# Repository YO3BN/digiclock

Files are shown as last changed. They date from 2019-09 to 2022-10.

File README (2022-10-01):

Configure:
==========

To prepare for compilation run the configure script with needed arguments.
Like the following:

./configure --uos ../../uOS --cpu atmega1284 --freq 1000000 --src lcd --src Si5351_ex

Compile:
========

make

To Clean:
=========

make clean
or
make distclean

How to flash:
=============

sudo avrdude -c usbtiny -p m1284 -U flash:w:./bin/firmware.hex:i
or
avrdude -P /dev/ttyUSB0 -c stk500v1 -b9600 -p m1284 -U flash:w:bin/firmware.hex:i

Read fuses (usually are shown when flashing)
==========

sudo avrdude -c usbtiny -p m1284 -U efuse:r:-:h
sudo avrdude -c usbtiny -p m1284 -U hfuse:r:-:h
sudo avrdude -c usbtiny -p m1284 -U lfuse:r:-:h

Their value must be:
avrdude: safemode: Fuses OK (E:FF, H:D8, L:62)

The original values were:
avrdude: safemode: Fuses OK (E:FF, H:99, L:62)

If the CPU frequency is 1MHz, the prescaler in uOS/arch/avr/atmega*/timers.c should be 1!

Write Hfuse
===========

To disable JTAG and activate the bootloader section at boot:
sudo avrdude -c usbtiny -p m1284 -U hfuse:w:0xD8:m

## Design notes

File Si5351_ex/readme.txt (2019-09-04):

This page contains some example code for the Si5351A synthesiser module chip.
There are a couple of other Si5351A libraries on the internet. However they
are either incomplete (don't go all the way from specifying a frequency, to
generating and setting the configuration registers), or quite over-complex.
Some are designed to cater for all the variants of the Si5351 (A/B/C) and all
the features. There's a Linux Si5351 driver but the code is very confusing and
anyway it does not seem well-suited to a limited-space microcontroller
environment.

So, with these C examples I have tried to keep it very simple, just to show
what needs to be done to get some output out of the Si5351A (only), and only
the 10-pin MSOP version with 3 outputs. From here, you can build on it, piece
by piece, to customise it for your application. So these examples generate a
10MHz signal on the Clk0 output, that's all. You can choose any frequency in
the range 1-150MHz, in the function call.

For frequencies under 1MHz, you need to employ the final divider stage in the
Si5351A, which can divide by powers of 2 from 1 to 128. So for example, if you
want 100kHz, then one way to do it is to configure the chip for a frequency of
1.6MHz, then configure the final division stage as divide-by-16 to get to
100kHz output. Using the division ratios, according to the datasheet, the
Si5351A can then generate low output frequencies from 8kHz to 1MHz.

For frequencies above 150MHz, and to the maximum specified frequency of 160MHz
according to the datasheet, some special configuration is required. I haven't
attempted to tackle that in this example code.
Useful documents

The Si5351A datasheet:
http://www.silabs.com/Support%20Documents/TechnicalDocs/Si5351-B.pdf
Manually generating an Si5351A register map:
http://www.silabs.com/Support%20Documents/TechnicalDocs/AN619.pdf

Application note AN619 "Manually generating an Si5351A register map" is much
more useful than the actual Si5351A datasheet. I refer to it often. There are
quite a lot of mistakes and confusions in both the datasheet and AN619 but all
of the information is actually in there and it can be decyphered.
Some theoretical discussion

The Si5351A is confugured using two signals, an I2C bus protocol. The QRP Labs
Si5351A module kit includes all the necessary pullups and level conversion to
run on a 5V microcontroller system. You only need to connect these two wires
to the AVR processor. It is important to understand the basic synthesis
mechanism of the Si5351A. There are really three stages to it:

1) A digital PLL multiplies the 27MHz crystal oscillator frequency up, to an
internal frequency; somewhere (that you configure) that must be in the range
600-900MHz. The multiplication factor is fractional, not an integer. The code
must configure all the registers that specify the integer part, and the
numerator/denominator of the fractional part. The integer part must be in the
range 15..90; the numerator 0..1048575 (20 bits), and the denominator
1..1048575 (also 20 bits). There are TWO PLLs available, PLL A and PLL B.

2) A divider stage divides this internal UHF frequency back down to the
desired output frequency. The division ratio is also fractional with 20-bit
fractional parts. However for best jitter performance the datasheet recommends
using even integers for the division factor. There are THREE "multisynth"
divider stages, one for each of the three Clk outputs of the Si5351A (other
variants of the Si5351A have 8 outputs, and various other input arrangements;
we aren't considering those here, we're keeping it simple, remember). Each
Multisynth divider can be fed by either of the two PLL outputs, you choose.

3) Finally there is also a final division stage for each output, which divides
by a power-of-2 factor of 1..128, this is needed for low frequency outputs in
the range 8kHz to 1MHz.

Since there are 2 PLLs and 3 outputs, and each output "multisynth" divider can
be fed from either of the two PLLs, if you want to set this up for multiple
outputs you have to do some tough thinking. If you stick to the "even integer"
divider, you don't really have THREE independent flexible output frequencies,
you have only two. Because two of those outputs are going to have to feed off
the same PLL. If there is not a convenient integral relationship between two
of the output frequencies, then for one of them you have to abandon the "even
integer division" rule for low jitter.

Anyway, I'm just saying. All of these things are considerations to take into
account. But not part of my simple simple example here.
Simple example code

The example code is written in C for AVR microcontrollers, I use the GCC
compiler in AVR Studio. It should be easy to use this on any AVR, or on the
Arduino platform. Only minor changes would be needed for other
microcontrollers.

There are TWO examples here. The first example allows you to use ANY I/O pins
of the processor to bit-bang as I2C. That gives a lot of flexibility, if you
happen to be using I/O pins other than the AVR's onboard I2C peripheral (they
call it the Two Wire interface in the Atmel datasheets and application notes),
or if you are using an AVR device that doesn't have an I2C peripheral onboard:
not all support I2C. In this example we use a very nice assembly language
library by Peter Fleury to take care of the I2C bit-banging. It works
perfectly!

The second example uses the AVR's internal I2C peripheral (which they call the
Two Wire interface, TWI, in the datasheets and application notes). That
assumes that in your application, your chosen AVR does have a TWI peripheral,
and that you aren't using those particular I2C pins of the processor for
something else, so you can afford to dedicate them to I2C purposes. This is
the ideal situation.

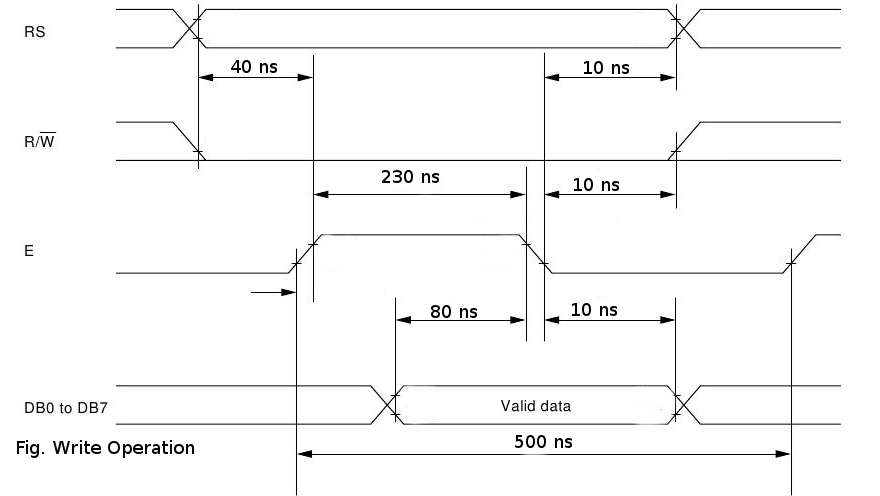
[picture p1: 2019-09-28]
hd44780/docs/write.png

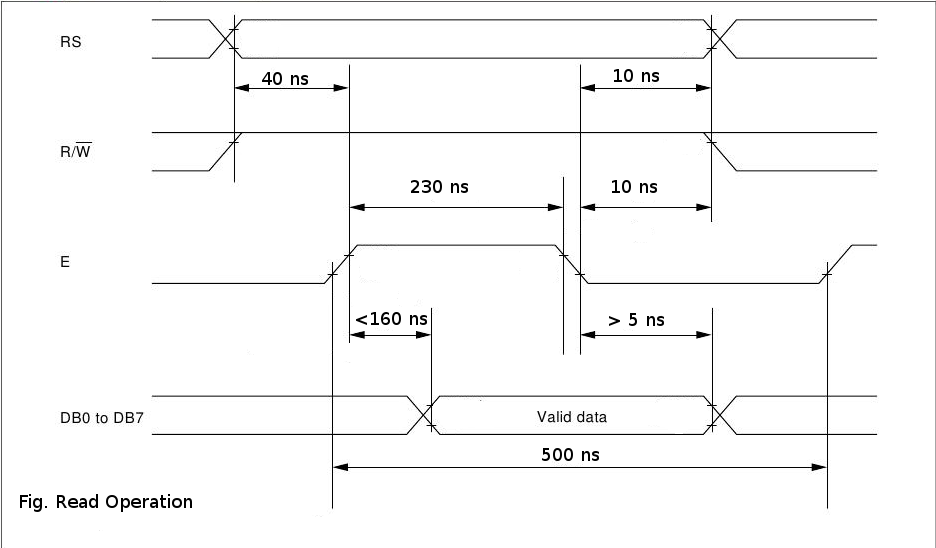
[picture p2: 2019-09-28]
hd44780/docs/read.png

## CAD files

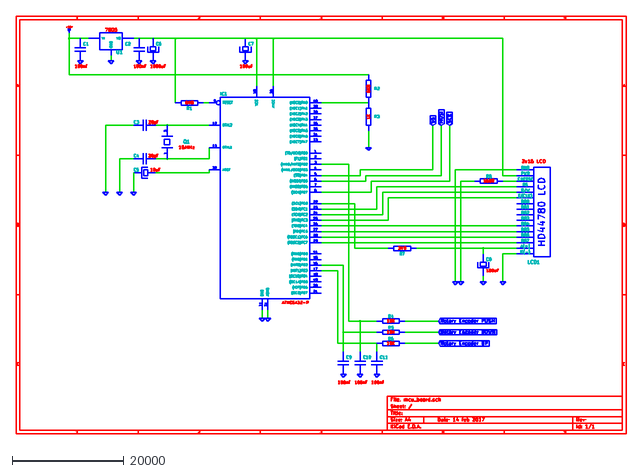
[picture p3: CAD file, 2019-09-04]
schematic/schematic.dxf
109000.0 x 74670.0

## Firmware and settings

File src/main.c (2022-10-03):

#include <stdio.h>
#include <stdlib.h>
#include <string.h>
#include <avr/io.h>
#include <util/delay.h>
#include <avr/sfr_defs.h>
#include <avr/interrupt.h>

#include "lcd.h"
#include "keypad.h"
#include "itu_table.h"
#include "si5351a.h"

#include "arch.h"
#include "kernel_api.h"

#include "drivers.h"
#include "uart.h"


typedef enum BFO_MODE_tag {
	LSB = 1,
	USB = 2,
} eBFO_Mode;


typedef enum IF_OPERATION_tag {
	IF_OPER_NONE = 0,
	IF_OPER_ADD = 1,
	IF_OPER_SUB = 2,
} eIF_OPERATION;


// TODO these should be stored in eeprom
#define IF_CENTER 10700000
#define IF_ECART 3000

static eBFO_Mode eBfo = LSB;
static eIF_OPERATION eIFOp = IF_OPER_ADD;
static int16_t IfEcart = IF_ECART;
static uint32_t if_center = IF_CENTER;
static uint8_t fine_tune = 0;

extern uint32_t xtalFreq;

typedef enum
{
	SCAN_NONE = 0,
	SCAN_WAIT,
	SCAN_UP,
	SCAN_DOWN,
} eScan;

static volatile eScan scan = SCAN_NONE;
static uint16_t scan_time = 5;

typedef enum eMENU_ENTRY_tag
{
	MENU_ENTRY_NONE = 0,
	MENU_ENTRY_FREQ_SET,
	MENU_ENTRY_FREQ_CURSOR,
	MENU_ENTRY_IF_ECART,
	MENU_ENTRY_BFO_MODE,
	MENU_ENTRY_BFO_OFFSET,
	MENU_ENTRY_BACKLIGHT,
	MENU_ENTRY_SICLK,
	MENU_ENTRY_SCNTIME,
	MENU_ENTRY_IFCENTER,
	MENU_ENTRY_EPROM_SAVE,
	MENU_ENTRY_EPROM_ERASE,
	MENU_ENTRY_EXIT,
}eMENU_ENTRY;

static eMENU_ENTRY eMenuEntry = MENU_ENTRY_FREQ_SET;


static int32_t offset_freq = 0;


struct frequency
{
	uint32_t hz;
	uint32_t step;
} frequency;


struct eprom_data
{
	uint32_t home_freq;
	uint32_t if_center;
	uint32_t si5351_qrtz;
	uint32_t if_width;
	int32_t  if_offset;
	// TODO: add checksum of all elements stored to eprom.
} eprom_data;


static volatile uint8_t event = 0;
extern volatile uint8_t keypad_event;
extern uint32_t xtalFreq;

#define	DIAL_UP		1
#define DIAL_DOWN	2
#define PUSH_BTN	3
#define KEYPAD		4

#define LCD_FREQ_POSITION	7
#define LCD_SMTR_POSITION	0x40


static volatile uint8_t encoder = 0;
static uint8_t show_agc_dB = 0;


/* the index is used as dB count. */
static uint16_t
agc_to_dB_table[] = {
	1023,
	894,
	718,
	650,
	608,
	575,
	549,
	526,
	505,
	487,
	469,
	453,
	435,
	420,
	406,
	393,
	380,
	368,
	356,
	345,
	334,
	323,
	312,
	301,
	293,
	284,
	276,
	268,
	260,
	252,
	245,
	238,
	231,
	224,
	219,
	213,
	208,
	203,
	198,
	194,
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
};


uint16_t audio_to_dB_table[] = {
	528,
	530,
	531,
	532,
	534,
	535,
	536,
	538,
	539,
	540,
	542,
	544,
	547,
	550,
	554,
	558,
	563,
	569,
	576,
	581,
	587,
	596,
	606,
	616,
	626,
	641,
	657,
	669,
	686,
	707,
	726,
	753,
	777,
	808,
	816,
	1023
};


ISR(PCINT3_vect)
{

static volatile uint8_t a = 0;
static volatile uint8_t isr = 0;
static volatile uint8_t byte = 0;
static volatile uint8_t x = 0;

	isr = ((PIND & 0b00110000) >> 4);
	if ((PIND & 0b00001000) == 0)
	{
		encoder = PUSH_BTN;
	}

	if (isr != a )
	{
		if (isr == 2 || isr == 0 || isr == 1)
		{
			byte |= isr;
			byte <<= 2;
			x++;
		}

		if ((x >= 3) && ((byte == 0x84) || (byte == 0x48)))
		{
			switch (byte)
			{
				case 0x84:
				encoder = DIAL_UP;
				break;

				case 0x48:
				encoder = DIAL_DOWN;
				break;

				default:
				break;
			}
			byte = 0;
			x = 0;
		}
		a = isr;
	}
}


uint8_t encoder_read(void)
{
	uint8_t ret = 0;

	switch (encoder)
	{
		case 1:
		case 2:
		case 3:
			ret = encoder;
			encoder = 0;
			break;

		default:
		break;
	}

	return ret;
}


void putch_freq(char c, char pos)
{
	lcd_command(LCD_SETDDRAMADDR | pos);
	lcd_write(c);
}

void show_freq(const char *s)
{
	char *p;
	char x = 0;
	char lcd_freq_pos = 15;

	/* p points to the end of the string */
	p = s + strlen(s) - 1;

	while (p >= s)
	{
		putch_freq(*p, lcd_freq_pos--);
		x++;

		if (!(x % 3) && (p - s > 0))
		{
			putch_freq(',', lcd_freq_pos--);
		}
		p--;
	}

	/* clear the rest of frequency field */
	//TODO: hardcoded 5 is the fifth character on the screen, after voltmeter */
	while (lcd_freq_pos >= 9)
	{
		putch_freq(' ', lcd_freq_pos--);
	}

	/* Fix for FineTune: point back to the end of row 1. */
	lcd_command(LCD_SETDDRAMADDR | 15);
}



void set_freq(char force)
{
	char buffer[16];
	uint32_t vfo_freq = frequency.hz;
	uint32_t bfo_freq = if_center;

	static uint32_t last_vfo_freq = 0;
	static uint32_t last_bfo_freq = 0;

	if (force)
	{
		last_vfo_freq = 0;
		last_bfo_freq = 0;
	}

	/* Adjust value of VFO FREQ to Intermediate Frequency Center */
	switch (eIFOp)
	{
	case IF_OPER_ADD:
		vfo_freq += if_center;
		break;

	case IF_OPER_SUB:
		vfo_freq = if_center - vfo_freq;
		break;

	case IF_OPER_NONE:
		break;

	default:
		return; //TODO fail
	}


	/* Adjust value of VFO FREQ regarding the LSB or USB mode */
	if (eBfo == LSB)
	{
		switch (eIFOp)
		{
		case IF_OPER_ADD:
			vfo_freq -= IfEcart / 2;
			bfo_freq -= IfEcart / 2;
		  vfo_freq += offset_freq;
		  bfo_freq += offset_freq;
			break;

		case IF_OPER_SUB:
			vfo_freq += IfEcart / 2;
			bfo_freq += IfEcart / 2;
		  vfo_freq -= offset_freq;
		  bfo_freq -= offset_freq;
			break;

		case IF_OPER_NONE:
			break;

		default:
			return; //TODO fail
		}
	}
	else if (eBfo == USB)
	{
		switch (eIFOp)
		{
		case IF_OPER_ADD:
			vfo_freq += IfEcart / 2;
			bfo_freq += IfEcart / 2;
		  vfo_freq -= offset_freq;
		  bfo_freq -= offset_freq;
			break;

		case IF_OPER_SUB:
			vfo_freq -= IfEcart / 2;
			bfo_freq -= IfEcart / 2;
		  vfo_freq += offset_freq;
		  bfo_freq += offset_freq;
			break;

		case IF_OPER_NONE:
			break;

		default:
			return; //TODO fail
		}
	}
	else return; //TODO fail

	/* Write BFO freq to synthesis chip */
	if (last_bfo_freq != bfo_freq)
	{
		si5351aSetFrequency_CLK2(bfo_freq);
		last_bfo_freq = bfo_freq;
	}

	/* Write VFO freq to synthesis chip */
	if (last_vfo_freq != vfo_freq)
	{
		si5351aSetFrequency_CLK0(vfo_freq);
		last_vfo_freq = vfo_freq;
	}

	/* Write freq to display in KHz units */
	sprintf(buffer, "%lu", frequency.hz / 1000);
	show_freq(buffer);

	if (!show_agc_dB)
	{
		show_itu(frequency.hz / 1000);
	}

	return;
}


static void inline eprom_save(void)
{
	eprom_data.home_freq = frequency.hz;
	eprom_data.si5351_qrtz = xtalFreq;
	eprom_data.if_center = if_center;
	eprom_data.if_width = IfEcart;
	eprom_data.if_offset = offset_freq;
	eeprom_write_block(&eprom_data, 0, sizeof(eprom_data));
}

static void process_keypad(char c)
{
	static char buffer[16];
	static char *ptr = buffer;
	static uint32_t step_bkp = 0;

	/* Check for special keys */
	switch (c)
	{

	case 'A':
		// 50 Hz fine tune
		if (!fine_tune)
		{
			fine_tune = 1;
			step_bkp = frequency.step;
			frequency.step = 50; // 50 Hz step

			/* set and show the cursor on the display. */
			lcd_enable_cursor();
			lcd_set_cursor(15, 0);
			return;
		}
		else
		{
			fine_tune = 0;
			frequency.step = step_bkp;

			/* remove the cursor from the display. */
			lcd_disable_cursor();
			return;
		}
		break;

	case 'B':
		//TODO optimize
		if (eBfo != USB)
		{
			eBfo = USB;
			set_freq(0);
			show_lsb_usb();
			return;
		}

		if (eBfo != LSB)
		{
			eBfo = LSB;
			set_freq(0);
			show_lsb_usb();
			return;
		}
		break;

	case 'C':
		if (scan == SCAN_NONE)
		{
			scan = SCAN_WAIT;
			lcd_enable_blinking();
			lcd_set_cursor(15, 0);
		}
		else
		{
			scan = SCAN_NONE;
			lcd_disable_blinking();
		}

		return;
		break;

	case 'D':
		// TODO
		if (!show_agc_dB)
		{
			show_agc_dB = 1;
			lcd_set_cursor(0, 1);
			lcd_printf("                ");
		}
		else
		{
			show_agc_dB = 0;
		}
		return;
		break;

	case '#':
		//TODO beautify/optimize this
		if (atol(buffer))
		{
			/* freq enetered in KHz units */
			frequency.hz = atol(buffer) * 1000;
			set_freq(0);
			memset(buffer, 0, sizeof(buffer));
			ptr = buffer;
			return;
		}
		break;

	case '*':
		//TODO
		if (strlen(buffer) > 0)
		{
			buffer[strlen(buffer) - 1] = '\0';
			ptr--;
		}
		break;

	default:
		if (isdigit(c))
		{
			*ptr = c;
			ptr++;

			/* check overflow */
			if (ptr == &buffer[sizeof(buffer)-1])
			{
				ptr = buffer;
				*ptr = c;
				ptr++;
			}
			*ptr = '\0';
		}
		break;
	}

	show_freq(buffer);
}


static void inline eprom_erase(void)
{
	memset(&eprom_data, 0xff, sizeof(eprom_data));
	eeprom_write_block(&eprom_data, 0, sizeof(eprom_data));
}


static void inline
clear_events(void)
{
	event = 0;
}


static void inline
process_event(void)
{
	if (!event) return;

	// set scan direction
	if (scan)
	{
		switch (scan)
		{
			case SCAN_WAIT:
				// initiating scan
				switch (event)
				{
				case DIAL_UP:
					scan = SCAN_UP;
					return;
					break;

				case DIAL_DOWN:
					scan = SCAN_DOWN;
					return;
					break;

				default:
					break;
				}
				break;

			case SCAN_DOWN:
				// change scan direction
				if (event == DIAL_UP)
				{
					scan = SCAN_UP;
				}
				break;

			case SCAN_UP:
				// change scan direction
				if (event == DIAL_DOWN)
				{
					scan = SCAN_DOWN;
				}
				break;

			default:
			break;
		}
	}

	char buffer[32];
	switch (event) {
		case KEYPAD:
			*buffer = keypad_get_key();
			if (*buffer)
			{
				process_keypad(*buffer);
			}
			break;

		case DIAL_UP:
			switch (eMenuEntry)
			{
			case MENU_ENTRY_FREQ_SET:
				frequency.hz += frequency.step;
				set_freq(0);
				break;

			case MENU_ENTRY_FREQ_CURSOR:
				//TODO: change the cursor accordingly
				frequency.step *= 10;
				if (frequency.step >= 10000000)
				{
					frequency.step = 10;
					//TODO: change the cursor accordingly
				}
				//TODO remove this
				lcd_command(LCD_SETDDRAMADDR | 0x40);
				sprintf(buffer, "STEP: %lu       ", frequency.step);
				lcd_printf(buffer);
				break;

			case MENU_ENTRY_IF_ECART:
				IfEcart += 100;
				set_freq(0);
				lcd_command(LCD_SETDDRAMADDR | 0x40);
				sprintf(buffer, "IFWIDTH: %d     ", IfEcart);
				lcd_printf(buffer);
				break;

			case MENU_ENTRY_BFO_MODE:
				eBfo = USB;
				set_freq(0);
				lcd_command(LCD_SETDDRAMADDR | 0x40);
				sprintf(buffer, "BFO: USB     ");
				lcd_printf(buffer);
				show_lsb_usb();
				break;

			case MENU_ENTRY_BFO_OFFSET:
				offset_freq += 100;
				set_freq(0);
				sprintf(buffer, "BFO OFFSET: %li     ", offset_freq);
				lcd_command(LCD_SETDDRAMADDR | 0x40);
				lcd_printf(buffer);
				break;

			case MENU_ENTRY_BACKLIGHT:
				//TODO beautify this
				DDRB = DDRB | 0b10000000;
				PORTB = PORTB | 0b10000000;

				sprintf(buffer, "LIGHT: ON    ");
				lcd_command(LCD_SETDDRAMADDR | 0x40);
				lcd_printf(buffer);
				break;

			case MENU_ENTRY_SICLK:
				xtalFreq += frequency.step;
				set_freq(1);
				sprintf(buffer, "SICLK: %lu", xtalFreq);
				lcd_command(LCD_SETDDRAMADDR | 0x40);
				lcd_printf(buffer);
				break;

			case MENU_ENTRY_SCNTIME:
				scan_time += 5;
				sprintf(buffer, "SCNTIME: %u    ", scan_time);
				lcd_command(LCD_SETDDRAMADDR | 0x40);
				lcd_printf(buffer);
				break;

			case MENU_ENTRY_IFCENTER:
				if_center += frequency.step;
				set_freq(1);
				sprintf(buffer, "IFCENTER: %lu    ", if_center);
				lcd_command(LCD_SETDDRAMADDR | 0x40);
				lcd_printf(buffer);
				break;

			case MENU_ENTRY_EPROM_SAVE:
				sprintf(buffer, "EPROM SAVING ...   ");
				lcd_command(LCD_SETDDRAMADDR | 0x40);
				lcd_printf(buffer);
				eprom_save();
				sprintf(buffer, "EPROM DONE         ");
				lcd_command(LCD_SETDDRAMADDR | 0x40);
				lcd_printf(buffer);
				break;

			case MENU_ENTRY_EPROM_ERASE:
				sprintf(buffer, "EPROM ERASING ...   ");
				lcd_command(LCD_SETDDRAMADDR | 0x40);
				lcd_printf(buffer);
				eprom_erase();
				sprintf(buffer, "EPROM ERASE DONE ");
				lcd_command(LCD_SETDDRAMADDR | 0x40);
				lcd_printf(buffer);
				break;

			default:
//				sprintf(buffer, "NOT IMPLEMENTED     ");
//				lcd_command(LCD_SETDDRAMADDR | 0x40);
//				lcd_printf(buffer);
				break;
			}


		break;

		case DIAL_DOWN:
			switch (eMenuEntry)
			{
			case MENU_ENTRY_FREQ_SET:
				frequency.hz -= frequency.step;
				set_freq(0);
				break;

			case MENU_ENTRY_FREQ_CURSOR:
				//TODO: change the cursor accordingly
				frequency.step /= 10;
				if (frequency.step < 10)
				{
					frequency.step = 1000000;
					//TODO: change the cursor accordingly
				}
				//TODO remove this
				lcd_command(LCD_SETDDRAMADDR | 0x40);
				sprintf(buffer, "STEP: %lu       ", frequency.step);
				lcd_printf(buffer);
				break;

			case MENU_ENTRY_IF_ECART:
				IfEcart -= 100;
				set_freq(0);
				lcd_command(LCD_SETDDRAMADDR | 0x40);
				sprintf(buffer, "IFWIDTH: %d     ", IfEcart);
				lcd_printf(buffer);
				break;

			case MENU_ENTRY_BFO_MODE:
				eBfo = LSB;
				set_freq(0);
				lcd_command(LCD_SETDDRAMADDR | 0x40);
				sprintf(buffer, "BFO: LSB     ");
				lcd_printf(buffer);
				show_lsb_usb();
				break;

			case MENU_ENTRY_BFO_OFFSET:
				offset_freq -= 100;
				set_freq(0);
				sprintf(buffer, "BFO OFFSET: %li     ", offset_freq);
				lcd_command(LCD_SETDDRAMADDR | 0x40);
				lcd_printf(buffer);
				break;

			case MENU_ENTRY_BACKLIGHT:
				//TODO beautify this
				DDRB = DDRB & 0b01111111;
				PORTB = PORTB & 0b01111111;

				sprintf(buffer, "LIGHT: OFF         ");
				lcd_command(LCD_SETDDRAMADDR | 0x40);
				lcd_printf(buffer);
				break;

			case MENU_ENTRY_SICLK:
				xtalFreq -= frequency.step;
				set_freq(1);
				sprintf(buffer, "SICLK: %lu", xtalFreq);
				lcd_command(LCD_SETDDRAMADDR | 0x40);
				lcd_printf(buffer);
				break;

			case MENU_ENTRY_SCNTIME:
				scan_time -= 5;
				sprintf(buffer, "SCNTIME: %u    ", scan_time);
				lcd_command(LCD_SETDDRAMADDR | 0x40);
				lcd_printf(buffer);
				break;

			case MENU_ENTRY_IFCENTER:
				if_center -= frequency.step;
				set_freq(1);
				sprintf(buffer, "IFCENTER: %lu    ", if_center);
				lcd_command(LCD_SETDDRAMADDR | 0x40);
				lcd_printf(buffer);
				break;

			case MENU_ENTRY_EPROM_SAVE:
				sprintf(buffer, "EPROM SKIPPING     ");
				lcd_command(LCD_SETDDRAMADDR | 0x40);
				lcd_printf(buffer);
				break;

			case MENU_ENTRY_EPROM_ERASE:
				sprintf(buffer, "EPROM ERASE SKIP ");
				lcd_command(LCD_SETDDRAMADDR | 0x40);
				lcd_printf(buffer);
				break;

			default:
//				sprintf(buffer, "NOT IMPLEMENTED     ");
//				lcd_command(LCD_SETDDRAMADDR | 0x40);
//				lcd_printf(buffer);
				break;
			}
		break;

		case PUSH_BTN:
			/* Do not enter into menu if scan is activated. */
			if (scan != SCAN_NONE)
			{
				break;
			}

			eMenuEntry++;
			switch (eMenuEntry)
			{
			case MENU_ENTRY_FREQ_SET:
				//frequency.hz -= frequency.step;
				//set_freq();
				break;

			case MENU_ENTRY_FREQ_CURSOR:
				//TODO remove this
				lcd_command(LCD_SETDDRAMADDR | 0x40);
				sprintf(buffer, "STEP: %lu       ", frequency.step);
				lcd_printf(buffer);
				break;

			case MENU_ENTRY_IF_ECART:
				lcd_command(LCD_SETDDRAMADDR | 0x40);
				sprintf(buffer, "IFWIDTH: %d     ", IfEcart);
				lcd_printf(buffer);
				break;

			case MENU_ENTRY_BFO_MODE:
				lcd_command(LCD_SETDDRAMADDR | 0x40);
				sprintf(buffer, "BFO: %s            ", eBfo == USB ? "USB" : "LSB");
				lcd_printf(buffer);
				break;

			case MENU_ENTRY_BFO_OFFSET:
				sprintf(buffer, "BFO OFFSET: %li     ", offset_freq);
				lcd_command(LCD_SETDDRAMADDR | 0x40);
				lcd_printf(buffer);
				break;

			case MENU_ENTRY_BACKLIGHT:
				sprintf(buffer, "LIGHT: ON/OFF     ");
				lcd_command(LCD_SETDDRAMADDR | 0x40);
				lcd_printf(buffer);
				break;
				
			case MENU_ENTRY_SICLK:
				sprintf(buffer, "SICLK: %lu", xtalFreq);
				lcd_command(LCD_SETDDRAMADDR | 0x40);
				lcd_printf(buffer);
				break;

			case MENU_ENTRY_SCNTIME:
				sprintf(buffer, "SCNTIME: %u     ", scan_time);
				lcd_command(LCD_SETDDRAMADDR | 0x40);
				lcd_printf(buffer);
				break;

			case MENU_ENTRY_IFCENTER:
				sprintf(buffer, "IFCENTER: %lu    ", if_center);
				lcd_command(LCD_SETDDRAMADDR | 0x40);
				lcd_printf(buffer);
				break;

			case MENU_ENTRY_EPROM_SAVE:
				sprintf(buffer, "EPROM SAVE?Y=UP");
				lcd_command(LCD_SETDDRAMADDR | 0x40);
				lcd_printf(buffer);
				break;

			case MENU_ENTRY_EPROM_ERASE:
				sprintf(buffer, "EPROM ERASE? UP  ");
				lcd_command(LCD_SETDDRAMADDR | 0x40);
				lcd_printf(buffer);
				break;

			default:
				sprintf(buffer, "                   ");
				lcd_command(LCD_SETDDRAMADDR | 0x40);
				lcd_printf(buffer);
				break;
			}

			if (eMenuEntry == MENU_ENTRY_EXIT)
			{
				eMenuEntry = MENU_ENTRY_NONE;
			}
			break;
	}
}


void show_lsb_usb(void)
{
	lcd_command(LCD_SETDDRAMADDR | 6);
	if (eBfo == USB)
	{
		lcd_printf("USB");
	}
	else if (eBfo == LSB)
	{
		lcd_printf("LSB");
	}
}


static void inline
frequency_init(void)
{
	frequency.hz = 3705000;
	frequency.step = 1000; // TODO: cannot be 50000 for example
}


static void
nonvolatile_data_init(void)
{
	memset(&eprom_data, 0, sizeof(eprom_data));
	eeprom_read_block(&eprom_data, 0, sizeof(eprom_data));

	if (eprom_data.home_freq != 0xffffffff)
	{
		frequency.hz = eprom_data.home_freq;
	}

	if (eprom_data.si5351_qrtz != 0xffffffff)
	{
		xtalFreq = eprom_data.si5351_qrtz;
	}

	if (eprom_data.if_center != 0xffffffff)
	{
		if_center = eprom_data.if_center;
	}

	if (eprom_data.if_width != 0xffffffff)
	{
		IfEcart = eprom_data.if_width;
	}

	if (eprom_data.if_offset != 0xffffffff)
	{
		offset_freq = eprom_data.if_offset;
	}
}


void events(void *p)
{
	while (1)
	{
		if (!event)
		{
			if(keypad_event)
			{
				event = KEYPAD;
			}
			else
			{
				event = encoder_read();
			}
		}

		process_event();
		clear_events();
		task_sleep(0, 1);
	}
}


void vbatt(void *v)
{
	adc_init();
	int16_t adc_value = 0;

	while (1)
	{
		task_sleep(0, 20);
		adc_value = adc_read(PA7);
		if (adc_value > -1) {
			show_voltage(adc_value);
		}
	}
}


float agc_to_dB(int16_t adc_value)
{
	/* TODO: beautify this function. */
	int x = 0;
	int y = 0;
	int dB = 0;
	float percentage = 0;

	if (adc_value < 0 || adc_value > 1023 ||
	adc_value >= agc_to_dB_table[0])
	{
		return 0;
	}

	/* Loop thru table till the value is found.
	 * Note: The index is used as decibell count.
	 */
	for (dB = 0; adc_value <= agc_to_dB_table[dB] && agc_to_dB_table[dB] != 0; dB++);

	/* After loop walk the index is one greater, need to decrement it by one. */
	if (dB)
	{
		dB--;
	}

	x = agc_to_dB_table[dB] - adc_value;
	y = agc_to_dB_table[dB] - agc_to_dB_table[dB + 1];

	percentage = x * 100 / y;
	percentage /= 100;

	return (dB + percentage);
}


float audio_to_dB(int16_t adc_value)
{
	/* TODO: beautify this function. */
	int x = 0;
	int y = 0;
	int dB = 0;
	float percentage = 0;

	if (adc_value < 0 || adc_value > 1023 ||
	adc_value <= audio_to_dB_table[0])
	{
		return 0;
	}

	/* Loop thru table till the value is found.
	 * Note: The index is used as decibell count.
	 */
	for (dB = 0; adc_value >= audio_to_dB_table[dB] && audio_to_dB_table[dB] != 1023; dB++);

	/* After loop walk the index is one greater, need to decrement it by one. */
	if (dB)
	{
		dB--;
	}

	x = audio_to_dB_table[dB + 1] - audio_to_dB_table[dB];
	y = adc_value - audio_to_dB_table[dB];
	percentage = y * 100 / x;
	percentage /= 100;

	return (dB + percentage);
}


float audio2dB(void)
{
	uint16_t i = 0;
	int16_t adc_value = 0;
	int16_t adc_value_last = 0;

	for (i = 0; i <= 512; i++)
	{
		adc_value = adc_read(PA1);
		if (adc_value < 0)
		{
			continue;
		}

		if (adc_value < 512)
		{
			// we are on the negative side,
			// thus transform it to positive.
			adc_value = 512 - adc_value;
		}

		if (adc_value > adc_value_last)
		{
			adc_value_last = adc_value;
		}
	}

	adc_value = adc_value_last;
	adc_value_last = 0;

	return (audio_to_dB(adc_value));
}

float agc2dB(void)
{
	int8_t z = 0;
	uint16_t i = 0;
	int16_t adc_value = 0;
	int16_t adc_value_last = 0;

	for (i = 0; i <= 10; i++)
	{
		adc_value = adc_read(PA0);
		if (adc_value < 0)
		{
			continue;
		}
		
		if (adc_value > adc_value_last)
		{
			adc_value_last = adc_value;
		}
	}

	adc_value = adc_value_last;
	adc_value_last = 0;

	return (agc_to_dB(adc_value));
}


void smeter(void *v)
{
	char buffer[32] = "";
	int16_t dB = 0;
	int16_t S9 = 48; // <-- this should be calibrated
	int8_t s = 0;
	int16_t dB_below_S9 = 0;
	int8_t i = 0;

	while (1)
	{
		if (show_agc_dB)
		{
			dB = ((int16_t) roundf(audio2dB())) + ((int16_t) roundf(agc2dB()));

			if (dB >= S9)
			{
				sprintf(buffer, "S9 +%2ddB ", dB - S9);
			}
			else
			{
				for (s = 0, i = 0, dB_below_S9 = S9 - 1; dB_below_S9 >= dB; dB_below_S9--, i++)
				{
					if (i == 6)
					{
						s++;
						i = 0;
					}
				}

				dB = 6 - i;
				s = 8 - s;

				sprintf(buffer, "S%d +%2ddB ", s, dB);
			}

			lcd_set_cursor(0, 1);
			lcd_printf(buffer);
			task_sleep(0, 1);
		}
		else
		{
			task_sleep(0, 1);
		}
	}
}


void dummy_scan(void *v)
{
	while (1)
	{
		task_sleep(0, scan_time);
		if (scan != SCAN_NONE)
		{
			// generating UP/DOWN event
			switch (scan)
			{
			case SCAN_UP:
				event = DIAL_UP;
				break;

			case SCAN_DOWN:
				event = DIAL_DOWN;
				break;

			default:
				break;
			}
		}
	}
}


void uart_echo(void *v)
{
  int ret = 0;
  char buffer[128] = "Type anything and press ENTER, you should receive the echo.\r\n";

  ret |= drv_init_uart();
  ret |= drv_open_uart();
  int z = DRVCTRL_UART_MODE_TXT;
  ret |= drv_ctrl_uart(DRVCTRL_SET, &z);
//  if (ret != DRV_STATUS_SUCCESS)
//    {
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
int main(void)
{
  /* Variables. */

  /* Initializations. */

	// turn on the backlight
	DDRB = 0b10000000;
	PORTB = 0b10000000;

    // turn on the display
	DDRD = 0b00000100;
	PORTD = 0b00000100;

	lcd_init();
	lcd_on();
	lcd_clear();

	frequency_init();
	nonvolatile_data_init();
	i2cInit();
	set_freq(0);
	si5351aOutputOff(SI_CLK1_CONTROL);
	keypad_init();
	encoder_init();

	show_lsb_usb();

  /* Setup task arguments. */

  /* Kernel initialization. */

  kernel_init();

  /* Creating tasks.
	 * TODO: decrease stack size for small tasks.
	 */

  task_create("Events", &events, NULL, 0);
  task_create("VBatt", &vbatt, NULL, 0);
  task_create("Dscan", &dummy_scan, NULL, 0);
	task_create("Smeter", &smeter, NULL, 0);
	task_create("UartEcho", &uart_echo, NULL, 0);

  /* Starting the never-ending kernel loop. */

  kernel_start();

  /* Should not reach here. */

  return 0;
}

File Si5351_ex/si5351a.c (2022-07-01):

// 
// Author: Hans Summers, 2015
// Website: http://www.hanssummers.com
//
// A very very simple Si5351a demonstration
// using the Si5351a module kit http://www.hanssummers.com/synth
// Please also refer to SiLabs AN619 which describes all the registers to use
//
#include <inttypes.h>
#include "i2c.h"
#include "si5351a.h"

uint32_t xtalFreq = 25000000;

//
// Set up specified PLL with mult, num and denom
// mult is 15..90
// num is 0..1,048,575 (0xFFFFF)
// denom is 0..1,048,575 (0xFFFFF)
//
void setupPLL(uint8_t pll, uint8_t mult, uint32_t num, uint32_t denom)
{
	uint32_t P1;					// PLL config register P1
	uint32_t P2;					// PLL config register P2
	uint32_t P3;					// PLL config register P3

	P1 = (uint32_t)(128 * ((float)num / (float)denom));
	P1 = (uint32_t)(128 * (uint32_t)(mult) + P1 - 512);
	P2 = (uint32_t)(128 * ((float)num / (float)denom));
	P2 = (uint32_t)(128 * num - denom * P2);
	P3 = denom;

	i2cSendRegister(pll + 0, (P3 & 0x0000FF00) >> 8);
	i2cSendRegister(pll + 1, (P3 & 0x000000FF));
	i2cSendRegister(pll + 2, (P1 & 0x00030000) >> 16);
	i2cSendRegister(pll + 3, (P1 & 0x0000FF00) >> 8);
	i2cSendRegister(pll + 4, (P1 & 0x000000FF));
	i2cSendRegister(pll + 5, ((P3 & 0x000F0000) >> 12) | ((P2 & 0x000F0000) >> 16));
	i2cSendRegister(pll + 6, (P2 & 0x0000FF00) >> 8);
	i2cSendRegister(pll + 7, (P2 & 0x000000FF));
}

//
// Set up MultiSynth with integer divider and R divider
// R divider is the bit value which is OR'ed onto the appropriate register, it is a #define in si5351a.h
//
void setupMultisynth(uint8_t synth, uint32_t divider, uint8_t rDiv)
{
	uint32_t P1;					// Synth config register P1
	uint32_t P2;					// Synth config register P2
	uint32_t P3;					// Synth config register P3

	P1 = 128 * divider - 512;
	P2 = 0;							// P2 = 0, P3 = 1 forces an integer value for the divider
	P3 = 1;

	i2cSendRegister(synth + 0,   (P3 & 0x0000FF00) >> 8);
	i2cSendRegister(synth + 1,   (P3 & 0x000000FF));
	i2cSendRegister(synth + 2,   ((P1 & 0x00030000) >> 16) | rDiv);
	i2cSendRegister(synth + 3,   (P1 & 0x0000FF00) >> 8);
	i2cSendRegister(synth + 4,   (P1 & 0x000000FF));
	i2cSendRegister(synth + 5,   ((P3 & 0x000F0000) >> 12) | ((P2 & 0x000F0000) >> 16));
	i2cSendRegister(synth + 6,   (P2 & 0x0000FF00) >> 8);
	i2cSendRegister(synth + 7,   (P2 & 0x000000FF));
}

//
// Switches off Si5351a output
// Example: si5351aOutputOff(SI_CLK0_CONTROL);
// will switch off output CLK0
//
void si5351aOutputOff(uint8_t clk)
{
	i2cSendRegister(clk, 0x80);		// Refer to SiLabs AN619 to see bit values - 0x80 turns off the output stage
}

// 
// Set CLK0 output ON and to the specified frequency
// Frequency is in the range 1MHz to 150MHz
// Example: si5351aSetFrequency(10000000);
// will set output CLK0 to 10MHz
//
// This example sets up PLL A
// and MultiSynth 0
// and produces the output on CLK0
//
void si5351aSetFrequency_CLK0(uint32_t frequency)
{
	uint32_t pllFreq;
	uint32_t l;
	float f;
	uint8_t mult;
	uint32_t num;
	uint32_t denom;
	uint32_t divider;
	static uint8_t n = 1;

	divider = 900000000 / frequency;// Calculate the division ratio. 900,000,000 is the maximum internal 
									// PLL frequency: 900MHz
	if (divider % 2) divider--;		// Ensure an even integer division ratio

	pllFreq = divider * frequency;	// Calculate the pllFrequency: the divider * desired output frequency

	mult = pllFreq / xtalFreq;		// Determine the multiplier to get to the required pllFrequency
	l = pllFreq % xtalFreq;			// It has three parts:
	f = l;							// mult is an integer that must be in the range 15..90
	f *= 1048575;					// num and denom are the fractional parts, the numerator and denominator
	f /= xtalFreq;					// each is 20 bits (range 0..1048575)
	num = f;						// the actual multiplier is  mult + num / denom
	denom = 1048575;				// For simplicity we set the denominator to the maximum 1048575

	if (n) {
		i2cSendRegister(149, 0);	//On some chips SpreadSpectrum is activated by default. We need to disable it.
		n = 0;
	}
									// Set up PLL A with the calculated multiplication ratio
	setupPLL(SI_SYNTH_PLL_A, mult, num, denom);
									// Set up MultiSynth divider 0, with the calculated divider. 
									// The final R division stage can divide by a power of two, from 1..128. 
									// reprented by constants SI_R_DIV1 to SI_R_DIV128 (see si5351a.h header file)
									// If you want to output frequencies below 1MHz, you have to use the 
									// final R division stage
	setupMultisynth(SI_SYNTH_MS_0, divider, SI_R_DIV_1);
									// Reset the PLL. This causes a glitch in the output. For small changes to 
									// the parameters, you don't need to reset the PLL, and there is no glitch
	// i2cSendRegister(SI_PLL_RESET, 0x20); //<- Very annoying when the frequency is changed too often or very fast.
									// Finally switch on the CLK0 output (0x4F)
									// and set the MultiSynth0 input to be PLL A
	i2cSendRegister(SI_CLK0_CONTROL, 0x4F | SI_CLK_SRC_PLL_A);
}
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

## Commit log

2019-09-04 initial commit; still coding
    [schematic.dxf, schematic.sch]
2019-09-05 added push button software filter
2019-09-07 implemented working keypad driver
2019-09-07 lowered push button delay
2019-09-08 print U for USB or L for LSB on screen; small ITU table change 20KHz
2019-09-21 Complete 0-30MHz ITU Table && Binary Search
    Added band titles from 14350 KHz to 30000 KHz.
    Created binary search algorithm in order to speed up the index lookup in ITU table.
    Fixed buffer overflow from keypad.
    [main.c]
2019-09-28 Disabled PLL RESET for VFO since it causes glitches in output.
    [si5351a.c]
2019-09-28 Added HD44780 driver sources; removed binary library; Untested
2020-03-02 Changed CPU frequency to 8MHz. Replaced 2x16 LCD library. Changed some GPIO pins for keypad, encoder, etc.
    [keypad.h]
2020-03-21 Hardcoded crystall frequency, center and width for Prototype V2.
2020-03-21 Fixed BFO Offset differences on LSB/USB
    [main.c]
2020-03-21 Removed cyclic lcd write of LSB/USB due noise interference.
    [main.c]
2022-06-17 -Added few notest in Readme file. -Added display turn on on PD2 pin. -Fixed backlight issue.
    [main.c]
2022-07-01 - Disabled SpreadSpectrum for newer chips. - Small modifications for Si5351 driver.
2022-07-04 FIRST COMMIT digiclock + uOS -digiclock now is compiling with uOS. -Tasks, encoder, display, keypad, Si5351, etc. are working. -Still coding ...
2022-09-11 Modified the SCAN feature. - Now the scan is working by pressing the C key and turn encoder Up or Down. - To stop the scanning the C key should be pressed again. - The D key has no function now.
2022-09-11 Added possibility to change SCAN direction on the fly using encoder up/down.
2022-09-22 Fixed comma display into frequency.
    [main.c]
2022-09-25 Added AGC voltage read and AGC to dB conversion.
2022-09-25 Added UART echo task.
2022-10-02 Reworked the ADC driver.
    [adc.c, main.c]
2022-10-03 Small changes of ADC integer types.
